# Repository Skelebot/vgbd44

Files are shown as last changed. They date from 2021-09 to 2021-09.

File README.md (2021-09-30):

# Vagabond 44 split keyboard (vgbd44)

An affordable, 44-key low-profile split mechanical keyboard using kailh choc switches with (optional) hot-swap and pure Rust firmware.

vgbd44 picture

Inspired by: 
 - [crkbd](https://github.com/foostan/crkbd) - overall keyboard shape, case mounting
 - [lily58](https://github.com/kata0510/Lily58) - additional thumb button
 - [keyseebee](https://github.com/TeXitoi/keyseebee) - firmware, switches

## Goals:
 - Portability
 - Very low profile - contributes towards portability, minimum hand strain
 - Affordable - no fancy and expensive parts, minimum 'extra' features
 - Easy to build - all of the components are hand-solderable
 - Easily sourceable components
 - Simple schematic and PCB
 - Simple and user-friendly firmware (written in Rust)
 - 3D printable case+plate - designed for painless printing even on non-professional printers
 - Optional hot-swap sockets - hot-swap is useful, but not everyone needs it
 - USB-C sockets - the new standard; one less reason to keep legacy cables around

## Non-goals:
 - No backlighting - less distracting keyboard, simpler design and firmware, easier to build
 - No ESD/overvoltage/etc protection - much more affordable, very rarely needed when the keyboard is used under normal conditions
 - No reversible PCB - heavily complicates PCB design and the building process; doesn't make manufacturing PCBs cheaper in most cases

### Extra features:
 - TRRS sockets at the top - doesn't require angled jacks, and the cable doesn't get in the way
 - +3V3, GND and a single GPIO pin breakout (for one-wire RGB LEDs or other custom features)
 - Test pads for debugging

## Resources
 - The firmware is located in the [vgbd44-firmware](https://github.com/Skelebot/vgbd44-firmware) repository.
   Head there for instructions on flashing and other firmware-related resources.
 - Case options and other notes on cases: [CASES.md](docs/CASES.md)
 - Layout info and printable layout diagrams: [LAYOUT.md](docs/LAYOUT.md)

## Parts list (BOM)
The parts list is also available [here](https://docs.google.com/spreadsheets/d/1f-E3JmmYUamYBCyl46FBLJGFHlAR0pfU8PB9eaqT7j0/edit?usp=sharing)
in spreadsheet form.

This table is a parts list for a full keyboard, with *estimate, rounded up* prices in EUR.

|Item |Remarks |Qty |Price (for exact qty) |
|---|---|--:|--:|
|[left PCB](eagle/CAMOutputs/left-gerber.zip), [right PCB](eagle/CAMOutputs/right-gerber.zip) | | 1, 1| 18.00|
|1N4148 diodes |MINIMELF package (or footprint-compatible) | 44| 0.50|
|100nF capacitor |0603 package | 6| 0.05|
|10nF capacitor |0603 package | 2| 0.01|
|1uF capacitor |0603 package | 4| 0.02|
|4.7uF capacitor |0603 package | 4| 0.02|
|10k resistor |0603 package | 2| 0.01|
|5.1k resistor |0603 package | 4| 0.02|
|MIC5504-3.3 or compatible |SOT23-5 package | 2| 0.24|
|6mm OFF-(ON) SMD button |for example PTS645SH50SMTR92 | 2| 0.40|
|PJ320A 3.5mm jack socket |easy to get on aliexpress | 2| 0.30|
|217B-AG01 USB-C socket | | 2| 4.00|
|STM32F042K6T6 or compatible |see notes in [firmware](https://github.com/Skelebot/vgbd44-firmware) | 2| 6.00|
|**Mechanical parts**|
|4mm M2 screws |for example M2X4/D7985-A2 | 20| 0.22|
|5mm M2 standoffs |for example TFF-M2X5/DR111 | 10| 2.00|

Which equals about **13.80 EUR** for a single keyboard (both halves).
For a full keyboard one would also (obviously) need switches and keycaps, which can
and usually are the most expensive part of a keyboard.

Other optional and/or extra parts are:
 - Kailh choc hotswap sockets (one per key)
 - USB-C cable (1)
 - TRRS cable (1)

## Photos:
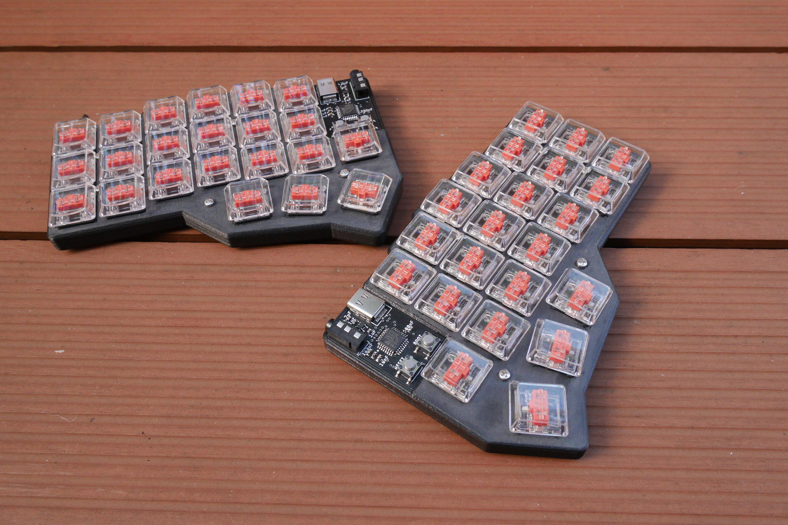
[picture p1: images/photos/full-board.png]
Left half complete

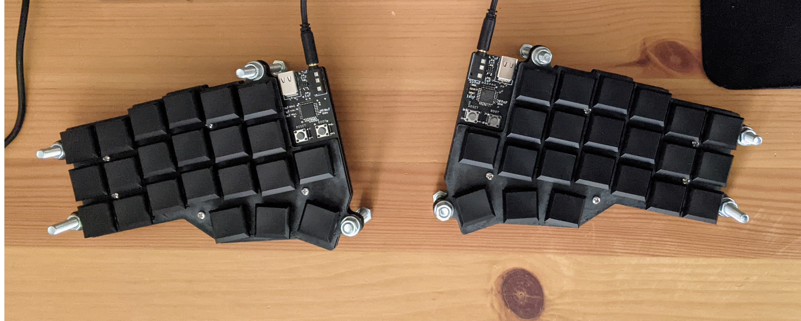
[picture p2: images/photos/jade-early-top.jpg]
Tented top view

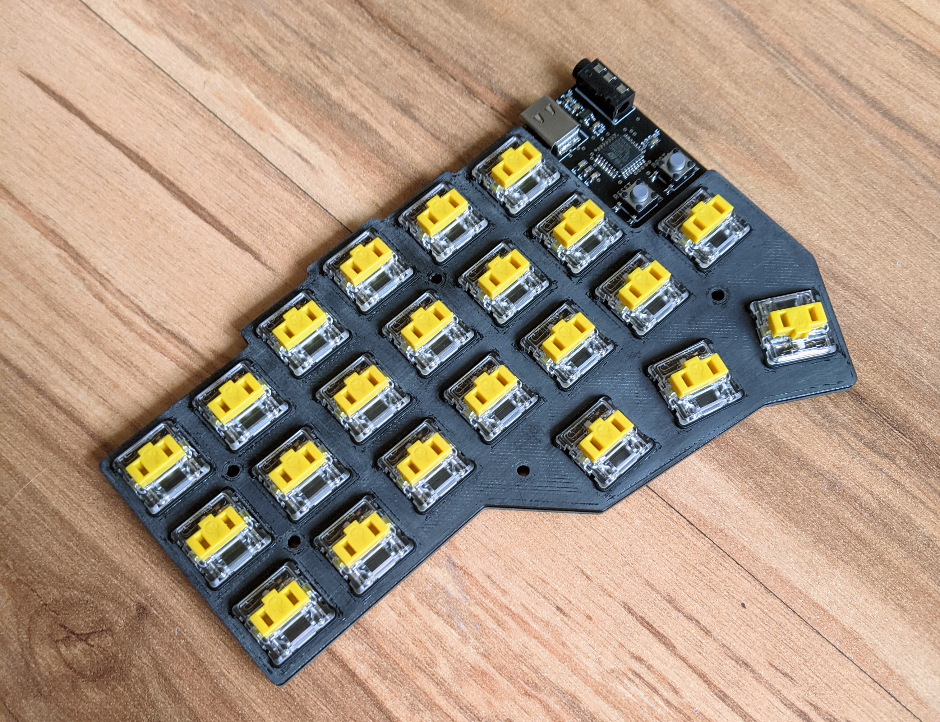
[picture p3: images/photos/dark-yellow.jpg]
Left half with kailh dark yellow switches


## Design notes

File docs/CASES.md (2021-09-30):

# Cases
3D design files for printing the cases are located in the [3D](../3D) folder.

Both the compact case and the tenting case have a 2mm thick plate, which is flush with both the PCB and the switch,
to ensure stability and that it doesn't bend, meaning that the flexibility of the material doesn't make much difference.

## Compact case
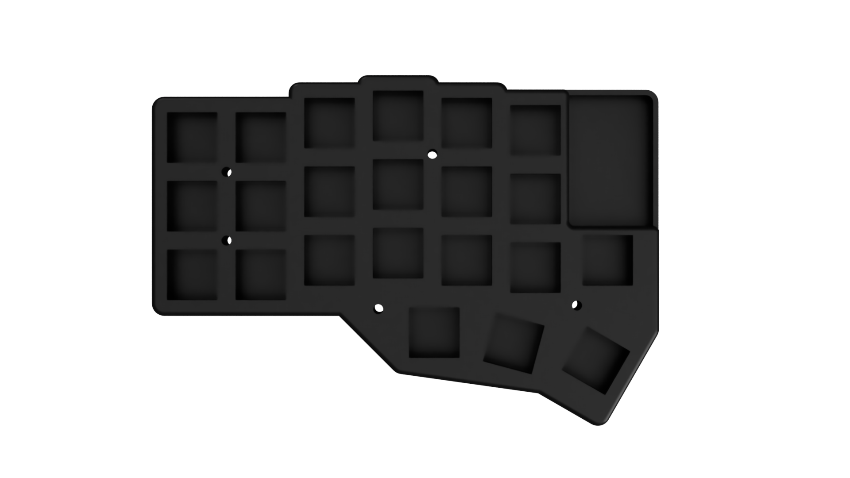
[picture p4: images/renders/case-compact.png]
Compact case


Minimal printable case - very light, minimal material needed

## Case with tenting snaps
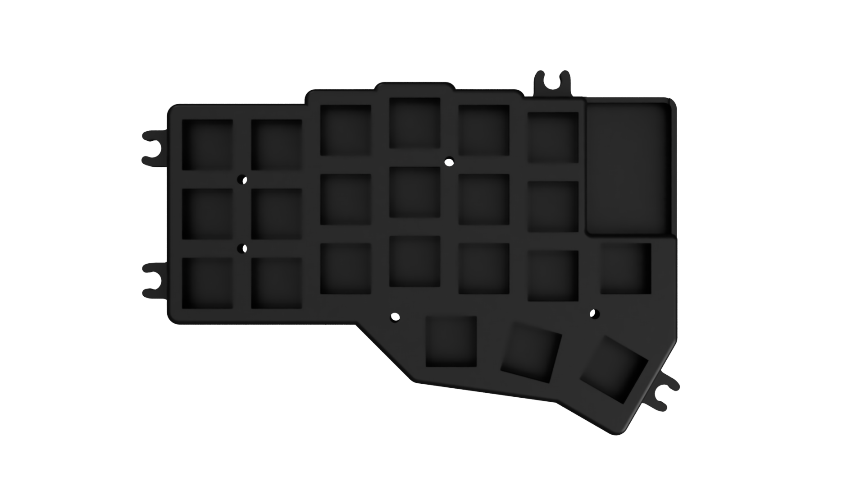
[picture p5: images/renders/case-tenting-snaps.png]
Case with tenting snaps


 - Identical as the compact case, but has 4 protrusions on the sides that fit standard M5 bolts.
 - Can be used with or without the "tenting poles" attached, and the poles can be attached without unscrewing nuts.
 - "Tenting poles" consist of a single M5 bolt of 30-60mm length with 2 nuts and optionally a washer or two.
 - A rubber bumper sticked on the head prevents the keyboard from sliding.

## Laser-cut "case"
The [drawings/](../drawings/) folder contains design files for a minimal laser-cut (or 3D-printed) case.
They were tested (3D-printed), but printing them (at least in plastic) is not recommended because those
plates will bend a lot.
When laser-cut (for example in aluminium) they should be quite solid and work just like a normal case.

## Photos
Tenting case
Assembled tenting case with legs attached

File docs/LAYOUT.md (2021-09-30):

# Layout

Example dvorak layout:

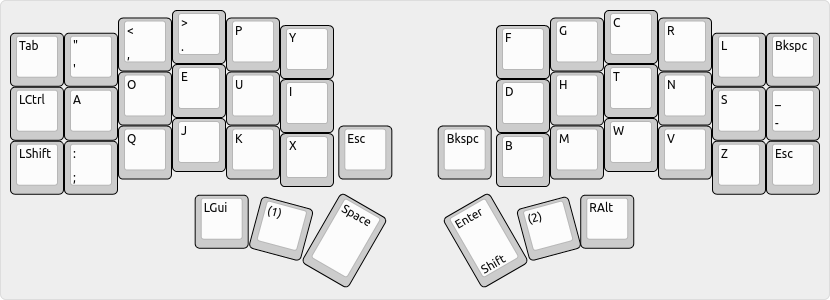
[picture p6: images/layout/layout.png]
Example dvorak layout


## SVG layout diagrams
 - [layout.svg](../images/layout/layout.svg) - a blank layout diagram
 - [layouts-blank.svg](../images/layout/layouts-blank.svg) - an A4 page filled with 4 blank layout diagrams,
   useful for prototyping layouts or writing them down when learning a new layout

## Keyboard Layout Editor links
**Note:** Key positions here are not exact. This should be only used for prototyping layouts.

 - [gist](http://www.keyboard-layout-editor.com/#/gists/9fd058138ca8fdef1ced3d48cb85c864)
 - [blank layout permalink](http://www.keyboard-layout-editor.com/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)
 - [dvorak permalink](http://www.keyboard-layout-editor.com/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,&_x:1%3B&=P&_x:5%3B&=G&_x:1%3B&=R%3B&@_y:-0.8600000000000001&x:5%3B&=Y&_x:3%3B&=F%3B&@_y:-0.8600000000000001%3B&=Tab%3B&@_y:-1&x:1%3B&=%22%0A'%3B&@_y:-1&x:13%3B&=L%3B&@_y:-1&x:14%3B&=Bkspc%3B&@_y:-0.41999999999999993&x:3%3B&=E&_x:7%3B&=T%3B&@_y:-0.8600000000000001&x:2%3B&=O&_x:1%3B&=U&_x:5%3B&=H&_x:1%3B&=N%3B&@_y:-0.8599999999999997&x:5%3B&=I&_x:3%3B&=D%3B&@_y:-0.8600000000000003%3B&=LCtrl&=A&_x:11%3B&=S&=%2F_%0A-%3B&@_y:-0.41999999999999993&x:3%3B&=J&_x:7%3B&=W%3B&@_y:-0.8599999999999999&x:2%3B&=Q&_x:1%3B&=K&_x:1.08%3B&=Esc&_x:0.8399999999999999%3B&=Bkspc&_x:1.08%3B&=M&_x:1%3B&=V%3B&@_y:-0.8600000000000003&x:5%3B&=X&_x:3%3B&=B%3B&@_y:-0.8599999999999999%3B&=LShift&=%2F:%0A%2F%3B&_x:11%3B&=Z&=Esc%3B&@_x:3.42%3B&=LGui&_x:6.140000000000001%3B&=RAlt%3B&@_r:15&rx:5.06&ry:3.92&y:-0.3599999999999999&x:-0.5%3B&=(1)%3B&@_r:30&rx:6.32&ry:4.06&y:-0.49999999999999956&x:-0.5&h:1.5%3B&=Space%3B&@_r:-30&rx:8.68&y:-0.49999999999999956&x:-0.5&h:1.5%3B&=Enter%0AShift%3B&@_r:-15&rx:9.94&ry:3.92&y:-0.3599999999999999&x:-0.5%3B&=(2))

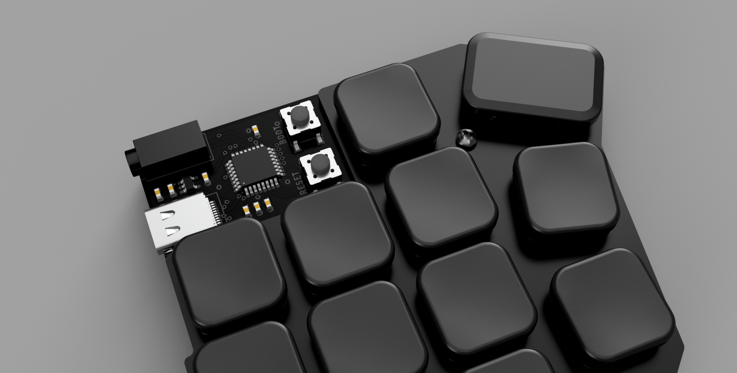
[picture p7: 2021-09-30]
images/renders/complete v14-top.png

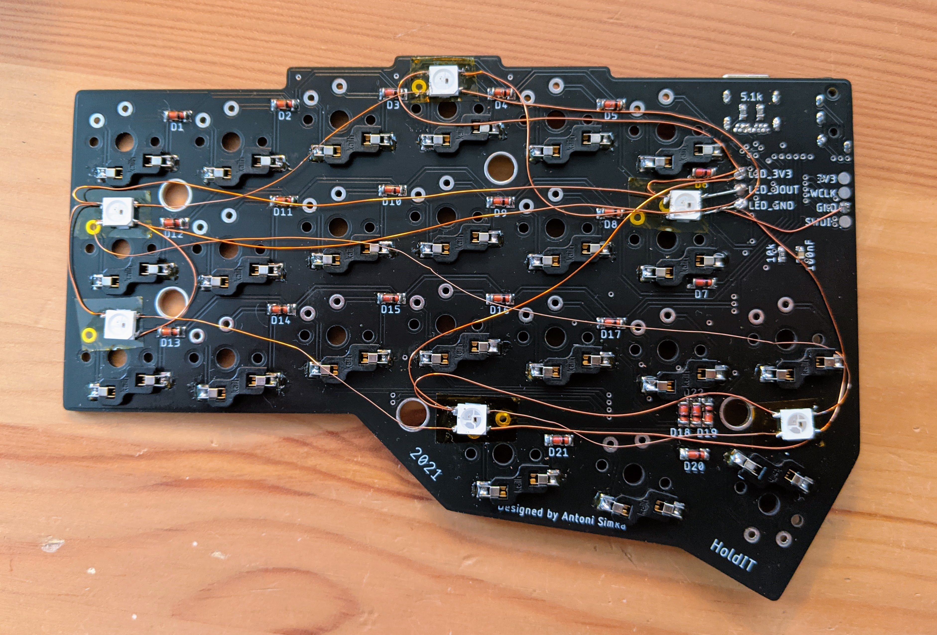
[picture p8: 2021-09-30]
images/photos/leds.jpg

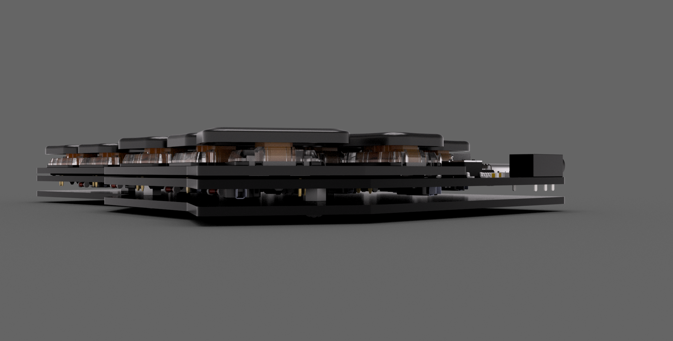
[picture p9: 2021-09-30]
images/renders/complete v14-low.png

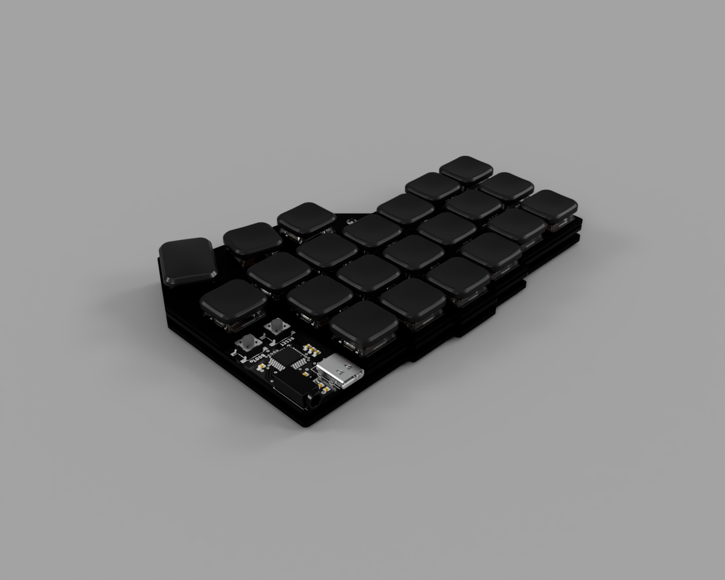
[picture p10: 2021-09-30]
images/renders/complete-left-iso.png

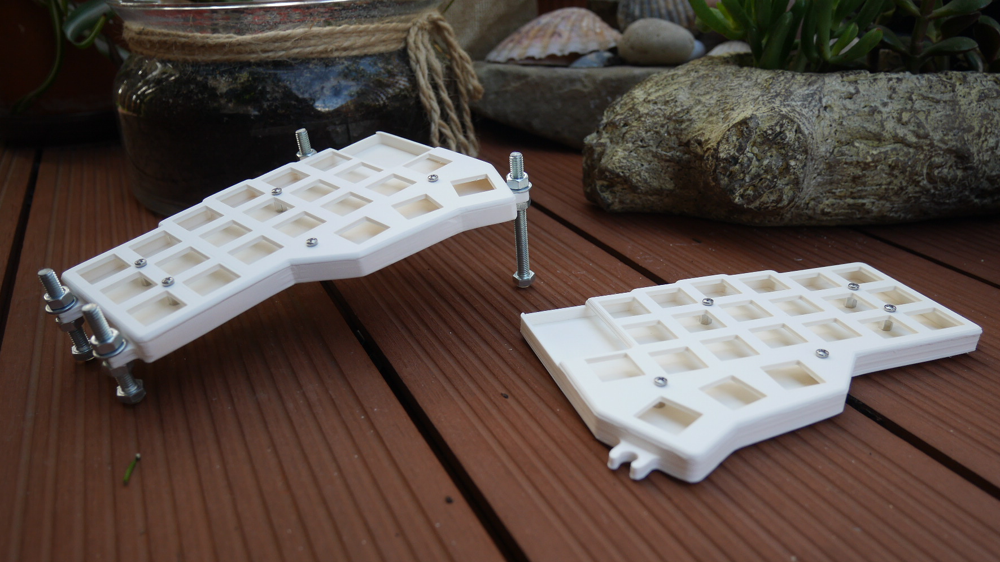
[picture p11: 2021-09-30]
images/photos/case.png

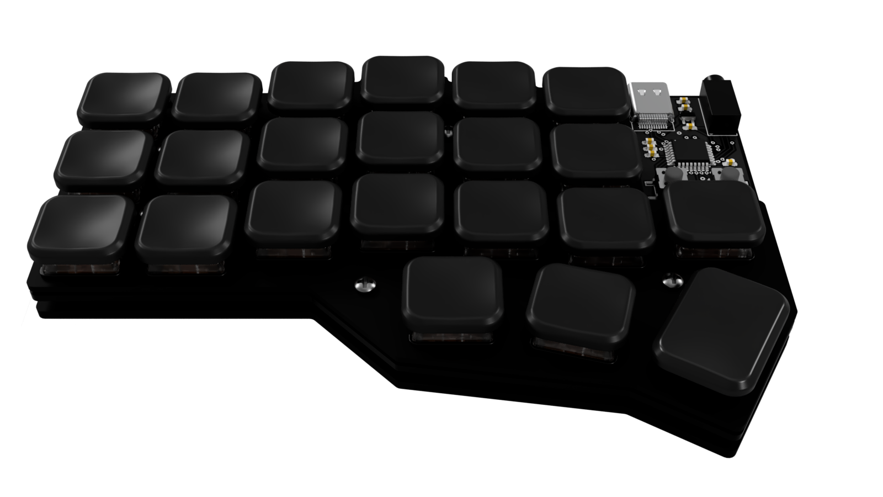
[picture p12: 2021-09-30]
images/renders/complete-left.png

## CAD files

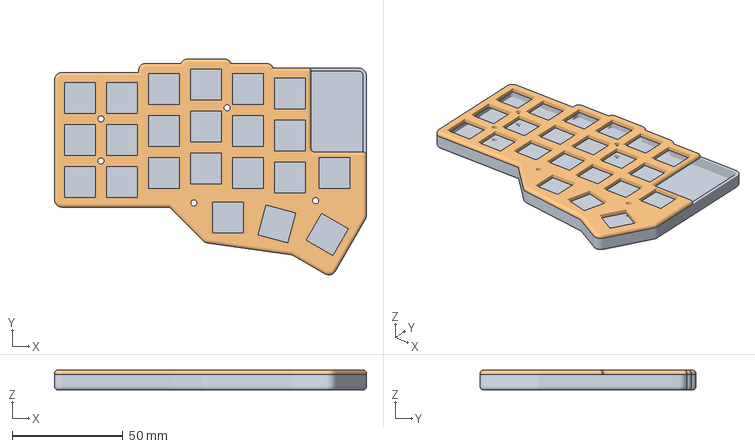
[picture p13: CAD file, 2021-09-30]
3D/print/case-compact.3mf
141.0 x 97.5 x 9.00 mm
case-bottom
case-top

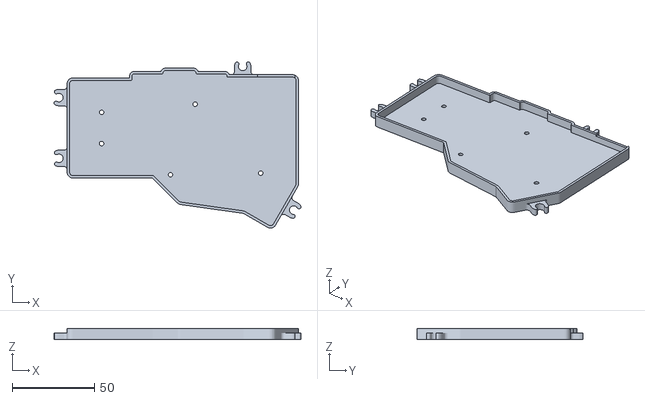
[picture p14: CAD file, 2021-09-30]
3D/print/STL/case-tenting-snap-bottom.stl
150.5 x 101.3 x 7.00

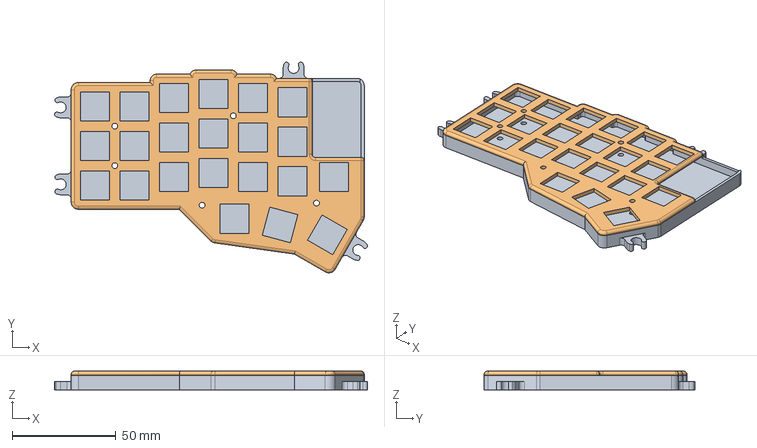
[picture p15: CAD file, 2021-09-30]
3D/step/case-tenting-snap.step
150.5 x 101.4 x 9.00 mm
case-bottom
case-top

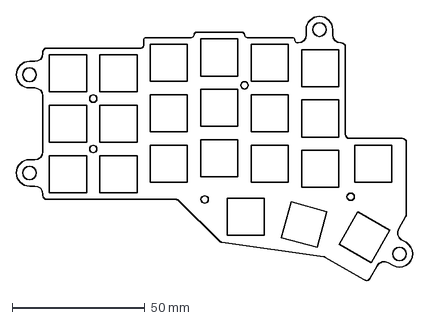
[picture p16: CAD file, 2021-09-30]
drawings/dxf/top_plate_tenting.dxf
149.4 x 99.6 mm

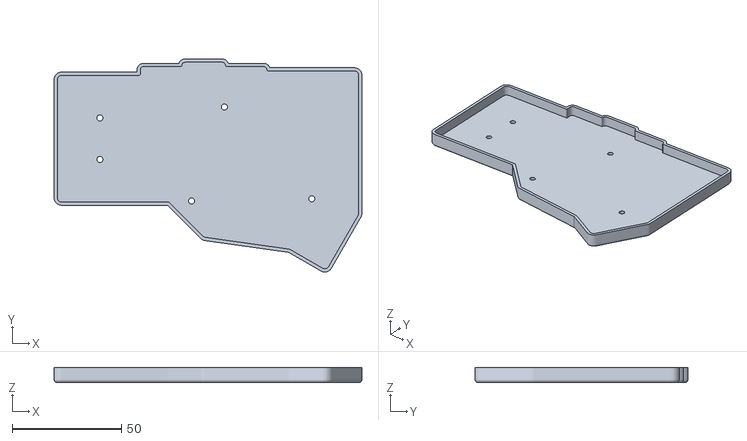
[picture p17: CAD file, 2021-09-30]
3D/print/STL/case-compact-bottom.stl
141.0 x 97.5 x 7.00

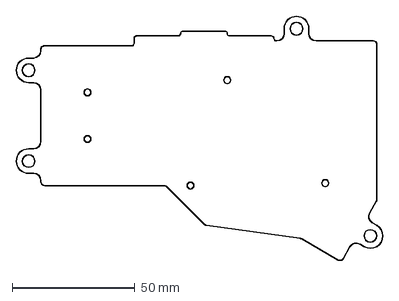
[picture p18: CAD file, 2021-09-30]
drawings/dxf/bottom_plate_tenting.dxf
149.4 x 99.6 mm

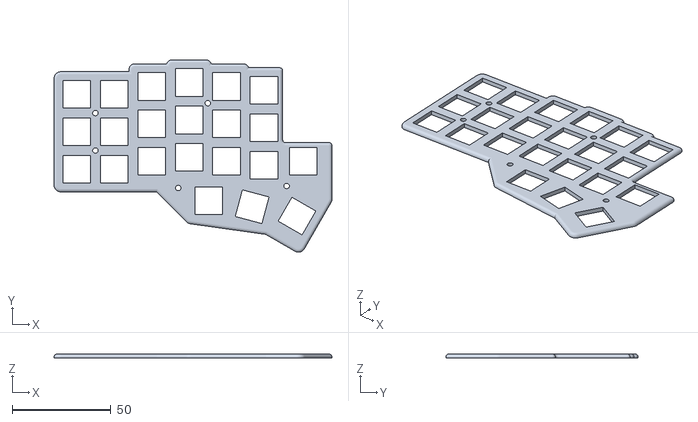
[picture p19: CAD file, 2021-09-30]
3D/print/STL/case-top.stl
141.0 x 97.5 x 2.00

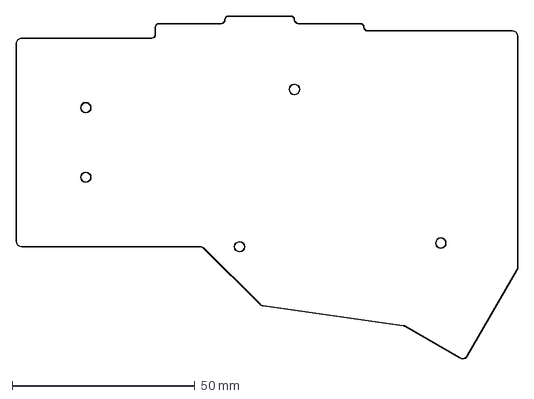
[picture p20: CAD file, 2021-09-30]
drawings/dxf/bottom_plate.dxf
137.0 x 93.6 mm

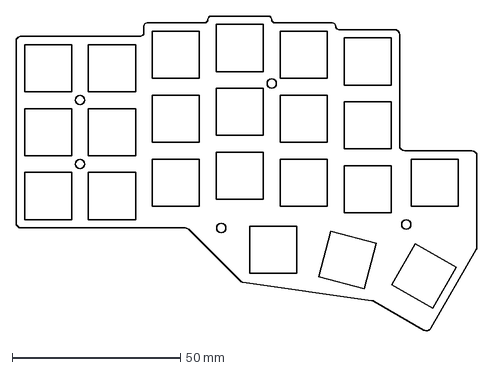
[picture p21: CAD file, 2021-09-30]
drawings/dxf/top_plate.dxf
137.0 x 93.6 mm

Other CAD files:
3D/fusion360/case-compact.f3d
3D/fusion360/case-tenting-snap.f3d
3D/print/case-tenting-snap.3mf
drawings/bottom_plate.dwg
drawings/bottom_plate_tenting.dwg
drawings/top_plate.dwg
drawings/top_plate_tenting.dwg

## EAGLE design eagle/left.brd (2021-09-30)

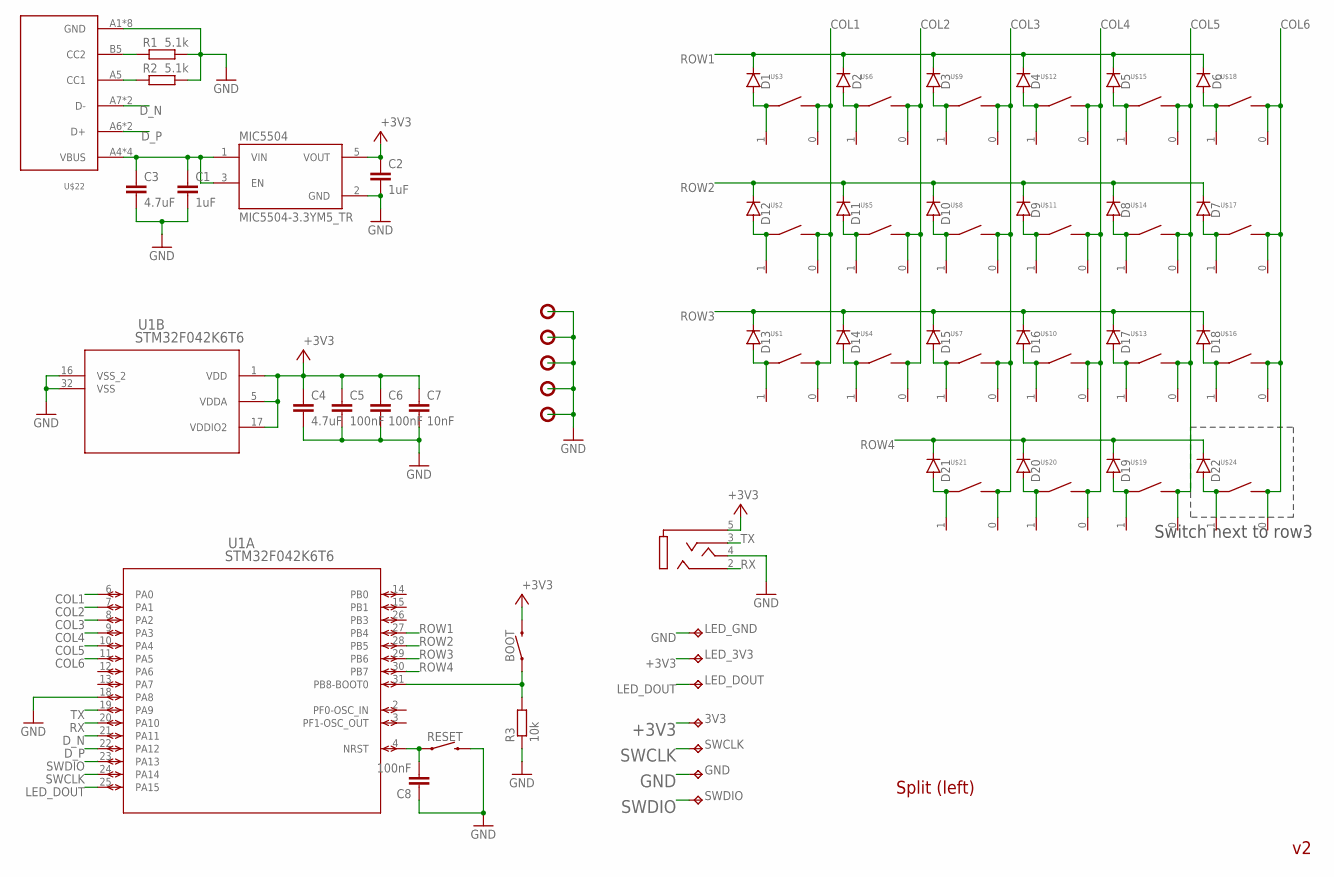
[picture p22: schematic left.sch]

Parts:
3V3: TPTP20R; TP20R
BOOT: MOMENTARY-SWITCH-SPST-SMD-6.2MM-TALL; TACTILE_SWITCH_SMD_6.2MM
C1, C2: 1uF; C0603
C3, C4: 4.7uF; C0603
C5, C6, C8: 100nF; C0603
C7: 10nF; C0603
D1, D2, D3, D4, D5, D6, D7, D8, D9, D10, D11, D12, D13, D14, D15, D16, D17, D18, D19, D20, D21, D22: DIODE-MINIMELF; MINIMELF
GND: TPTP20R; TP20R
LED_3V3: TPTP20R; TP20R
LED_DOUT: TPTP20R; TP20R
LED_GND: TPTP20R; TP20R
MIC5504: MIC5504-3.3YM5_TR; SOT95P280X145-5N
R1, R2: 5.1k; R0603
R3: 10k; R0603
RESET: MOMENTARY-SWITCH-SPST-SMD-6.2MM-TALL; TACTILE_SWITCH_SMD_6.2MM
SWCLK: TPTP20R; TP20R
SWDIO: TPTP20R; TP20R
U1: STM32F042K6T6; LQFP-32
U$1, U$2, U$3, U$4, U$5, U$6, U$7, U$8, U$9, U$10, U$11, U$12, U$13, U$14, U$15, U$16, U$17, U$18, U$19, U$20, U$21, U$24: CHOC-CHOC-1U; CHOC-1U
U$22: 217B-AG01
U$23: PJ320A
U$25, U$26, U$27, U$28, U$29, U$30, U$31, U$32, U$33, U$34, U$35, U$36, U$37, U$38, U$39, U$40, U$41, U$42, U$43, U$44, U$45, U$46: SOCKET; CHOC-SOCKET
U$47, U$48, U$49, U$50, U$51: MOUNTING-PADHOLE-M2-OFFSET; HOLE-M2-OFFSET

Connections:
+3V3: 3V3.TP, BOOT.B2 (2), C2.1, C4.1, C5.1, C6.1, C7.1, LED_3V3.TP, MIC5504.5 (VOUT), U1.1 (VDD), U1.5 (VDDA), U1.17 (VDDIO2), U$23.5
COL1: U1.6 (PA0), U$1.1, U$2.1, U$3.1, U$25.0, U$30.0, U$41.0
COL2: U1.7 (PA1), U$4.1, U$5.1, U$6.1, U$26.0, U$31.0, U$42.0
COL3: U1.8 (PA2), U$7.1, U$8.1, U$9.1, U$21.1, U$27.0, U$32.0, U$37.0, U$43.0
COL4: U1.9 (PA3), U$10.1, U$11.1, U$12.1, U$20.1, U$28.0, U$33.0, U$38.0, U$44.0
COL5: U1.10 (PA4), U$13.1, U$14.1, U$15.1, U$19.1, U$29.0, U$34.0, U$39.0, U$45.0
COL6: U1.11 (PA5), U$16.1, U$17.1, U$18.1, U$24.1, U$35.0, U$36.0, U$40.0, U$46.0
D_N: U1.21 (PA11), U$22.A7 (D-), U$22.B7 (D-)
D_P: U1.22 (PA12), U$22.A6 (D+), U$22.B6 (D+)
GND: C1.2, C2.2, C3.2, C4.2, C5.2, C6.2, C7.2, C8.1, GND.TP, LED_GND.TP, MIC5504.2 (GND), R1.2, R2.2, R3.1, RESET.B2 (2), U1.16 (VSS_2), U1.18 (PA8), U1.32 (VSS), U$22.A1 (GND), U$22.A12 (GND), U$22.B1 (GND), U$22.B12 (GND), U$22.SHELL (GND), U$22.SHELL1 (GND), U$22.SHELL2 (GND), U$22.SHELL3 (GND), U$23.4, U$47.P$1, U$48.P$1, U$49.P$1, U$50.P$1, U$51.P$1
LED_DOUT: LED_DOUT.TP, U1.25 (PA15)
unnamed: R2.1, U$22.A5 (CC1)
unnamed: R1.1, U$22.B5 (CC2)
unnamed: C1.1, C3.1, MIC5504.1 (VIN), MIC5504.3 (EN), U$22.A4 (VBUS), U$22.A9 (VBUS), U$22.B4 (VBUS), U$22.B9 (VBUS)
unnamed: D1.A, U$3.0, U$41.1
unnamed: D2.A, U$6.0, U$42.1
unnamed: D12.A, U$2.0, U$30.1
unnamed: D11.A, U$5.0, U$31.1
unnamed: BOOT.A2 (1), R3.2, U1.31 (PB8-BOOT0)
unnamed: C8.2, RESET.A2 (1), U1.4 (NRST)
unnamed: D18.A, U$16.0, U$36.1
unnamed: D10.A, U$8.0, U$32.1
unnamed: D9.A, U$11.0, U$33.1
unnamed: D8.A, U$14.0, U$34.1
unnamed: D7.A, U$17.0, U$35.1
unnamed: D22.A, U$24.0, U$40.1
unnamed: D17.A, U$13.0, U$29.1
unnamed: D13.A, U$1.0, U$25.1
unnamed: D14.A, U$4.0, U$26.1
unnamed: D15.A, U$7.0, U$27.1
unnamed: D16.A, U$10.0, U$28.1
unnamed: D20.A, U$20.0, U$38.1
unnamed: D3.A, U$9.0, U$43.1
unnamed: D4.A, U$12.0, U$44.1
unnamed: D5.A, U$15.0, U$45.1
unnamed: D6.A, U$18.0, U$46.1
unnamed: D21.A, U$21.0, U$37.1
unnamed: D19.A, U$19.0, U$39.1
ROW1: D1.C, D2.C, D3.C, D4.C, D5.C, D6.C, U1.27 (PB4)
ROW2: D7.C, D8.C, D9.C, D10.C, D11.C, D12.C, U1.28 (PB5)
ROW3: D13.C, D14.C, D15.C, D16.C, D17.C, D18.C, U1.29 (PB6)
ROW4: D19.C, D20.C, D21.C, D22.C, U1.30 (PB7)
RX: U1.20 (PA10), U$23.2
SWCLK: SWCLK.TP, U1.24 (PA14)
SWDIO: SWDIO.TP, U1.23 (PA13)
TX: U1.19 (PA9), U$23.3

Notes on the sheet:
Split (left)
Switch next to row3

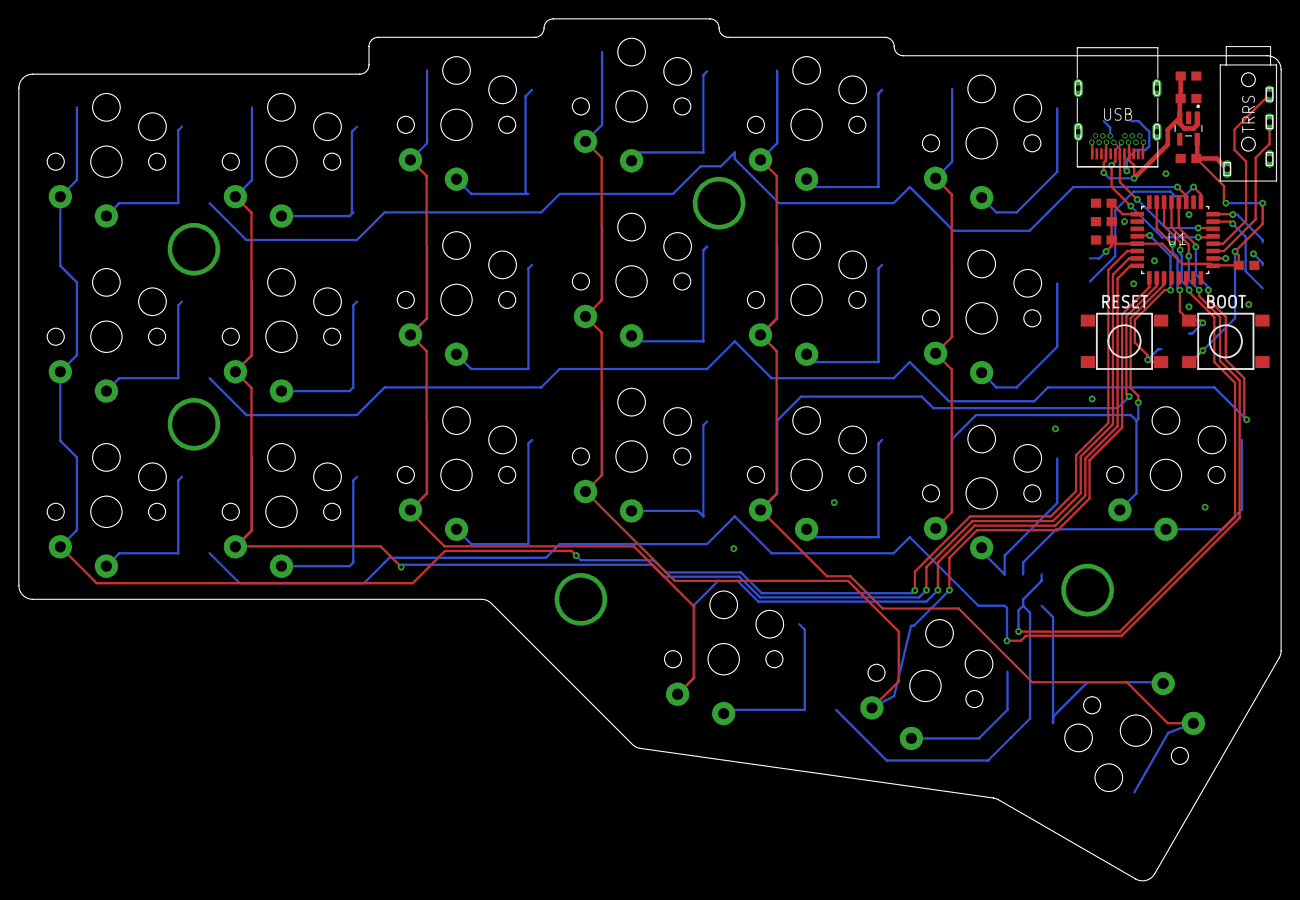
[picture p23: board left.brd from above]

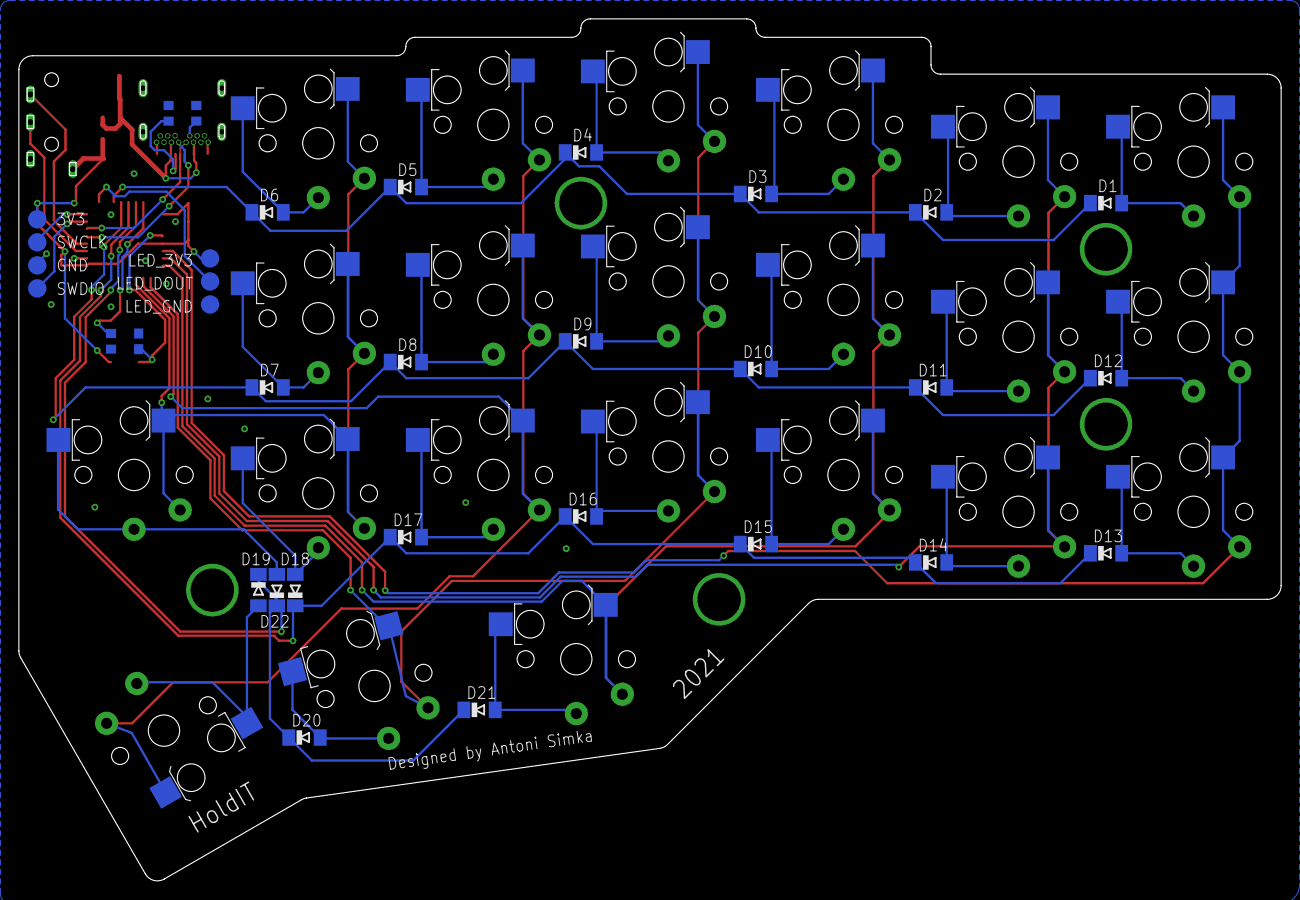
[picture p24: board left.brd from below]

Board: 2 copper layers, 137.0 x 93.6 mm, 95 parts (55 on the bottom side), 46 nets.

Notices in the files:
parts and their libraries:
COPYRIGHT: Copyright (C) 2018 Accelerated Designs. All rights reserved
